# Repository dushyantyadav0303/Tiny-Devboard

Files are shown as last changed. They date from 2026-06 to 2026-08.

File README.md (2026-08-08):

<h1 align="center">
<br> 
<br> Tiny Devboard <br>
</h1>
<div align="center">
  

</div>

<h4 align="center">
A pocket-sized development board built for rapid prototyping, experimentation, and embedded systems development. Its compact USB form factor makes it easy to carry, plug in, and start building wherever inspiration strikes.
</h4>

<div align="center">





</div>

<p align="center">
  <a href="#about-the-project">About</a> •
  <a href="#repository-structure">Structure</a> •
  <a href="#schematic">Schematic</a> •
  <a href="#pcb">PCB</a> •
  <a href="#cad">CAD</a> •
  <a href="#Render">Render</a> •
  <a href="#bill-of-materials">BOM</a> •
  <a href="#license">License</a> •
  <a href="#credits">Credits</a>
</p>  
<p
  align="center">
  

</p>

<br>
<br>
<p align=center>
  
</p>

## About the Project
**Tiny Devboard** is a pocket-sized development board built for rapid prototyping, experimentation, and embedded systems development. Its compact USB form factor makes it easy to carry, plug in, and start building wherever inspiration strikes.

### Specifications

| Item | Details |
|---|---|
| MCU | ATSAMD21E18A-AU |
| Wireless | ESP-12S |
| USB | Type-A |
| Logic Voltage | 3.3V |
| RGB LED | APA102-2020 |
| Programming | UF2 / SWD |

### Features

- **ATSAMD21E18A-AU (32-bit ARM Cortex-M0+)**
- **ESP-12S (ESP8266 Wi-Fi)**
- **USB Type-A Port**
- **RGB Status LED**
- **Compact Form Factor**

## Repository Structure

- `src/PCB/` — EasyEDA project sources
- `src/cad/` — mechanical CAD sources
- `production/pcb/` — PCB fabrication files (Gerbers, BOM, Pick & Place)
- `production/cad/` — 3D-printing files (.3mf)
- `GETTING_STARTED/` — Setup guides, firmware installation, and board bring-up documentation
- `Journal/` — DevLogs With Timestamp
- `Firmware/` — Demo firmware, utilities, and firmware releases for Tiny DevBoard

## Schematic


Source : `src/PCB/Sch`
SCH_Schematic1_1-P1_2026-06-14

## PCB 
Source : `src/PCB/Pcb`
~ https://oshwlab.com/dushyant0303/project_kbwfubeg
<div align="center">

| Front PCB | Back PCB |
|---|---|
|  |  |
|  |  |

</div>

## CAD


A Encloser Case for Tiny Devboard. Case consists of 6 interlocking Hook that are secured them, allowing the enclosure to be assembled without screws or Glue makes it easy assembly.

- source: `src/cad/`
<div align="center">
<table>
<tr>
<td valign="bottom">
</td>
<td valign="bottom">I
</table>
</div>

### 3D-printable Production files are available in:
- source: `production/cad/`

## Render 


<div align="center">
<table>
<tr>
<td valign="bottom">
</td>
<td valign="bottom">
</table>
</div>

## Bill of Materials

Source: `production/pcb/bom.xlsx`

| No. | Quantity | Comment | Designator | Footprint | Value | Price (in INR) | Purchase |
| --- | --- | --- | --- | --- | --- | --- | --- |
| 1 | 1 | 1uf | C1 | C0603 | 1uf | 1.5 | [Buy](https://robu.in/product/cs2012x7r105k500nre-samwha-50v-1uf-x7r-±10-0805-multilayer-ceramic-capacitors-mlcc-smd-smt-rohs/) |
| 2 | 1 | 1.5k | R7 | R0805_NEW | 1.5k | 0.4 | [Buy](https://robu.in/product/wr08x152jtl-walsin-125mw-thick-film-resistors-150v-±100ppm-℃-±5-1-5kω-0805-chip-resistor-surface-mount-rohs/) |
| 4 | 3 | 0.1uf | C8,C5,C7 | C0805 | 0.1uF | 2.1 | [Buy](https://robu.in/product/cl21b104kcc5pnc-samsung-cap-ceramic-0-1uf-100v-x7r-10-pad-smd-0805-omd-cap-125c-automotive-aec-q200-t-r/) |
| 5 | 1 | USB type A port | USB1 | USB-AM-TH_AM90 |  | 14 | [Buy](https://robu.in/product/u-g-04wd-w-03-hroparts-1a-1-4p-male-40℃85℃-type-a-plugin-usb-connectors-rohs/) |
| 6 | 1 | APA102-2020 SuperLED | U2 | LED-SMD_6P-L2.0-W2.0-APA102-2020-SUPERLED |  | 17 | [Buy](https://www.lcsc.com/product-detail/C22439302.html) |
| 7 | 1 | ATSAMD21E18A-AU | U1 | TQFP-32_L7.0-W7.0-P0.80-LS9.0-BL |  | 460 | [Buy](https://www.lioncircuits.com/parts/ATSAMD21E18A-AU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) |
| 8 | 1 | ESP-12S | U4 | WIRELM-SMD_ESP-12S |  | 199 | [Buy](https://robu.in/product/esp-12s/) |
| 9 | 1 | HT7833 | U3 | SOT-89_L4.5-W2.5-P1.50-LS4.2-BR |  | 46 | [Buy](https://robu.in/product/ht7833-holtek-semicon-500ma-fixed-3-3v-positive-electrode-8v-sot-89-3-voltage-regulators-linear-low-drop-out-ldo-regulators-rohs/) |
| 10 | 1 | ZX-PZ1.0-1-6PZZ | Gn +3 Rx Tx Clk Dio | HDR-TH_6P-P1.00-V-F |  | 19 | [Buy](https://robu.in/product/1-month-warranty-884/) |
| 11 | 2 | 0 | R8,R9 | R0603 | 0 | 0.96 | [Buy](https://robu.in/product/ac0805jr-070rl-yageo-res-thick-film-0805-0-ohm-pad-smd-t-r-automotive-aec-q200/) |
| 13 | 2 | LED_0402-R | LED3,LED4 | LED0805-RD_GREEN_C0805YGC |  | 2.6 | [Buy](https://robu.in/product/xl-2012vrc-xinglight-5ma-90mcd-red-lens-615nm630nm-positive-stick-red-120-75mw-2-7v3-3v-0805-led-indication-discrete-rohs/) |
| 14 | 3 | 10uF | C3,C4,C6 | C0805 | 10uF | 1.15 | [Buy](https://robu.in/product/cs2012x7r106k100nre-samwha-10v-10uf-%c2%b110-0805-multilayer-ceramic-capacitors-mlcc-smd-smt-rohs/) |
| 15 | 3 | TSA010A2518A | BOOT,SW1,SW2 | SW-SMD_L4.0-W3.0-LS5.0 |  | 2.1 | [Buy](https://robu.in/product/tsa010a2010a02-bzcn-3mm-2mm-50ma-round-button-standing-paste-3-9mm-100gf-12v-smd-tactile-switches-rohs/) |
| 16 | 6 | 10K | R5,R1,R2,R3,R4,R6 | R0805 |  | 0.61 | [Buy](https://robu.in/product/ac0805fr-7w10kl-yageo-250mw-thick-film-resistors-%c2%b1100ppm-%e2%84%83-%c2%b11-10k%cf%89-0805-chip-resistor-surface-mount-rohs/) |
| 17 | 1 | PCB | | |  | 190  | [Buy](https://jlcpcb.com)|

> [!NOTE]
> Price As of August 8, 2026 
> & It not Include the Shipping fee <br/>

## License

Licensed under MIT — you can use this commercially, modify, and distribute 
with proper attribution. See [LICENSE](LICENSE) file.

## Contributing

Contributions, improvements, and remixes are welcome! Please read the [CONTRIBUTING.md](CONTRIBUTING.md) guide to get started.

## Credits
<div align="center">
  



 
</div>

This project was created during a [Hack Club](https://hackclub.com) event [Macondo](https://macondo.hackclub.com).
- **[EasyEDA](https://easyeda.com)** - PCB design and schematic capture
- **[Fusion 360](https://www.autodesk.com/products/fusion-360)** - Cad Designing
- **[Blender](https://www.blender.org)** - Render
- **[@NotARoomba](https://github.com/notaroomba) & [@Gabouin](https://github.com/Gabouin)** - Readme template

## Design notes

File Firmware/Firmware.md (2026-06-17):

# Tiny DevBoard Firmware Docs

## About

**Tiny DevBoard Firmware** is a demo firmware for the Tiny DevBoard development board Testing, Diagnosing and Check there Capability.
## Workflow 
1. Serial print Banner
2. Initialize GPIO/UART/RGB
3. Check Module Connections
4. Display Hardware Spec
5. Run Self-Test
``` 
Loop
 ├── RGB Animation v
 ├── Status Report
 └── WiFi Scan
 ```
## Quick Start

- Download [Arduino IDE](https://www.arduino.cc/en/software)
- Go to Tools → Board Manager
- Search for "SAMD"
- Install Arduino SAMD Boards by Arduino
- Install Required Libraries
- Go to Sketch → Include Library → Manage Libraries
- Search and install: Adafruit DotStar by Adafruit
- Tools Menu:
``` 
├── Board: Adafruit Trinket M0
├── Serial Monitor Baud: 115200
└── COM Port: 
```
- Open Demo_Firmware.ino file in Arduino IDE
- Click Upload 
- Open Tools → Serial Monitor At baudRate 115200  To See Output

## Expected Output
```
=============================================
                 Tiny Devboard
=============================================
 Firmware Version : v1.0.0
 Build Date       : 10 Jun 2026
 Author           : dushyant.yadav0303

Hola Hackers! It's me tiny devboard
Tiny DevBoard is starting up...

- Starting rgb animation
- Checking USB connection

Resetting Wifi module ...
 - Wifi module detected Successfully

=======================================
System Information
=======================================
Board Name    : Tiny Devboard
MCU           : ATSAMD21E18A-AU
CPU Frequency : 48 MHz
Flash Memory  : 256 KB
SRAM Memory   : 32 KB

 - Wifi module detected Successfully

=========================================
 Board ready to Rock!
=========================================
```

##  Code Structure
```
TinyDevBoard_Firmware.ino
├── Libraries
├── Pin Definitions & Constants
├── Global Variables
├── Function Prototypes
├── setup()
├── loop()
├── Initialization Functions
│   ├── initializeSerial()
│   ├── initializeHardware()
│   ├── initializeRGB()
│   └── initializeESP()
├── Display Functions
│   ├── displayStartupBanner()
│   ├── displaySystemInfo()
│   └── displayStatusReport()
├── RGB Animation Functions
│   ├── updateRGBAnimation()
│   ├── rainbowCycle()
│   ├── breathingAnimation()
│   └── pulseAnimation()
├── ESP Communication Functions
│   ├── communicateWithESP()
│   ├── performWifiScan()
│   ├── sendESPCommand()
│   └── readESPResponse()
└── Utility Functions
    └── getUptimeSeconds()
```

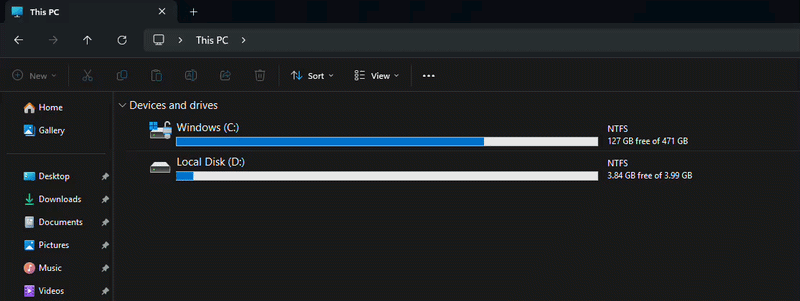
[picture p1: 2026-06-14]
assets/603955411-69c8cde0-e02c-4d08-941e-243680734509.gif

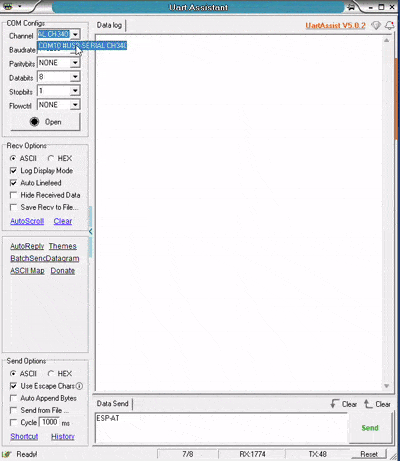
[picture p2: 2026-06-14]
assets/604092013-d6aead8e-e24d-442f-a11d-7670309c13b5.gif

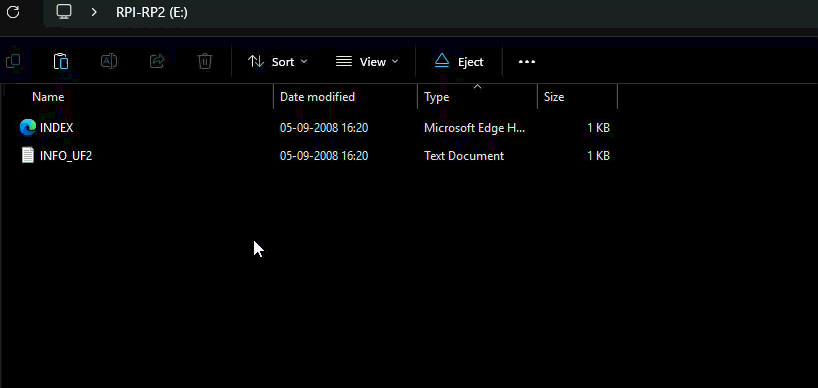
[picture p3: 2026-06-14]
assets/603960065-23f23f05-d857-41ca-997a-91e4c60d457d.gif

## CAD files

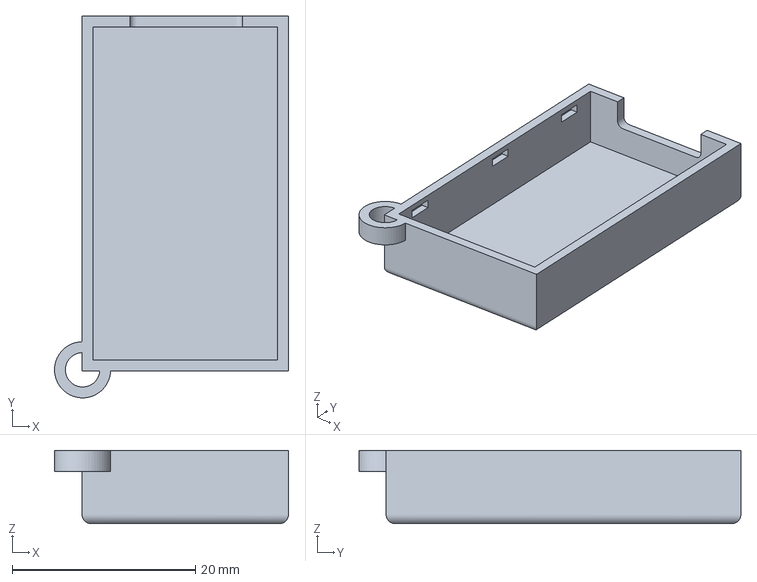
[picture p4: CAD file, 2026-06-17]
production/cad/Bottom.3mf
25.5 x 41.6 x 8.00 mm

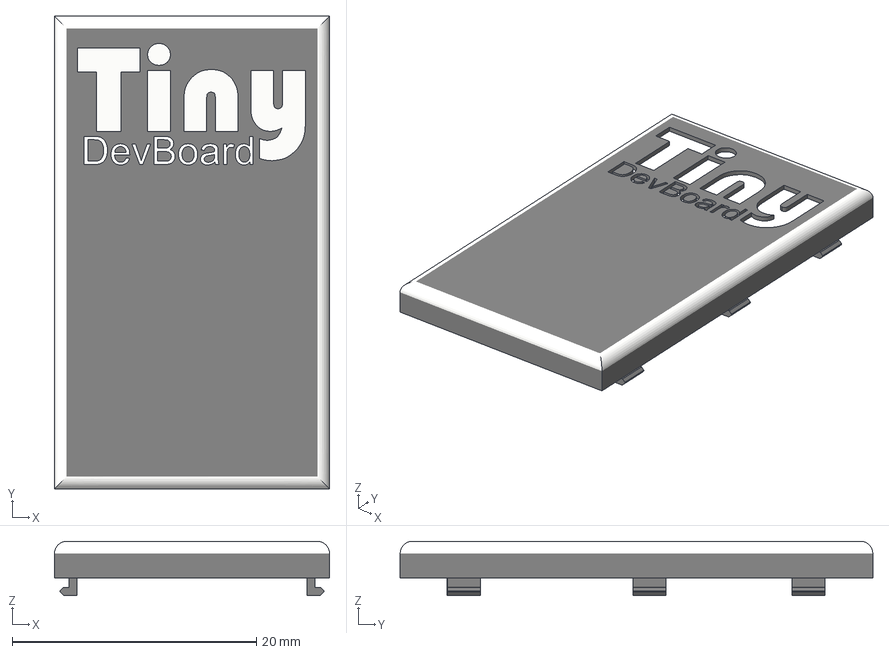
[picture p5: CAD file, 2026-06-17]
production/cad/TOP.3mf
22.5 x 38.7 x 4.45 mm

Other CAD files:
production/cad/stl/Bottom.stl
production/cad/stl/TOP.stl

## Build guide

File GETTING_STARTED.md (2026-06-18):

# Getting Started

## Table of Contents

* [Prerequisites](#prerequisites)

  * [Hardware Requirements](#hardware-requirements)
  * [Software Requirements](#software-requirements)
* [Board Connections](#board-connections)

  * [USB](#usb)
  * [SWD](#swd)
  * [UART](#uart)
* [ATSAMD21 Setup](#atsamd21-setup)

  * [Install Bootloader](#install-bootloader)
  * [Verify Bootloader](#verify-bootloader)
  * [Upload Firmware](#upload-firmware)
* [ESP-12S Setup](#ESP-12S-Setup)

  * [Check Existing Firmware](#check-existing-firmware)
  * [Flash Firmware](#flash-firmware)
* [First Power-On Test](#first-power-on-test)
* [Troubleshooting](#troubleshooting)
* [What's Next?](#What's-Next?)

## Prerequisites
### Hardware Requirements
- [Usb to TTL Converter](https://github.com/dushyantyadav0303/USB-TO-TTL-Convertor)
- [Usb to SWD Converter](https://robocraze.com/products/st-link-v2-v2-1-usb-c-programmer-and-debugger-for-stm32-microcontrollers-7semi)
- [Jumper Wire](https://robocraze.com/products/jumper-wire-set-m2m-m2f-f2f-40-pcs-each)

### Software Requirements

- [Espressif flash download tool](https://docs.espressif.com/projects/esp-test-tools/en/latest/esp32/production_stage/tools/flash_download_tool.html)
- [UartAssist](https://www.nitwo.com/en/download/UartAssist.html)

## Board Connections

### USB
Connect Devboard Usb Port Directly to your Pc


### SWD
> [!WARNING]
> Always Set the adapter TO 3.3v Logic. 

       Devboard                    Usb to SWD
    ┌───────────────┐           ┌─────────────┐
    │ SWDIO         ├──────────►│ SWDIO       │
    │ SWCLK         ├──────────►│ SWCLK       │
    │ 3V3           ├──────────►│ 3V3         │
    │ GND           ├──────────►│ GND         │
    └───────────────┘           └─────────────┘


### UART
> [!WARNING]
> Always Set the adapter TO 3.3v Logic. 

       Devboard                    Usb to TTL
    ┌─────────────┐             ┌─────────────┐
    │          TX ├────────────►│ RX          │
    │          RX │◄────────────┤ TX          │
    │         GND ├────────────►│ GND         │
    │        3.3v ├────────────►│ Vcc         │
    └─────────────┘             └─────────────┘


## ATSAMD21 Setup

### Install Bootloader
1. Connect USB to SWD Converter To DevBoard [Given Above](#swd)
2. Download the [UF2 bootloader](https://downloads.circuitpython.org/bin/trinket_m0/en_US/adafruit-circuitpython-trinket_m0-en_US-10.3.0-alpha.2.uf2)
3. Flash the Bootloader 

### Verify Bootloader
1. Connect the Board via [USB](#usb)
2. Quickly press the RESET button twice 
 

3. Devboard detected in the PC As a external Storage 
Recording2026-06-06223643-ezgif com-speed

### Upload Firmware
1. Connect the Board via [USB](#usb)
2. Quickly press the RESET button twice
4. Prepare your firmware in .uf2
5. Paste your firmware in Detected External storage 


## ESP-12S-Setup

### Check Existing Firmware

1. Connect USB to TTL Converter To DevBoard [Given Above](#UART)
2. Download Serial Port Terminal ex. [UartAssist ](https://www.nitwo.com/en/download/UartAssist.html)
3. Configure it According to this 


4. Send AT command 
Recording 2026-06-07 035755 - Trim

If you Response Ok Then it is Perfect 
If not then Follow next [Flash Firmware](#flash-firmware)

### Flash Firmware

1. Download [Firmware](https://espressif-docs.readthedocs-hosted.com/projects/esp-at/en/release-v2.3.0.0_esp8266/AT_Binary_Lists/ESP8266_AT_binaries.html) 
2. Download [Espressif flash download tool](https://docs.espressif.com/projects/esp-test-tools/en/latest/esp32/production_stage/tools/flash_download_tool.html) 
3. Connect USB to TTL Converter To DevBoard [Given Above](#UART)
4. Open Flashing tool 
- Select Esp8266 & Developer mode 


- Select the firmware with hex code 0x0 & And select the Correct com Port


5. Esp-12s into Flash mode


- Press and hold the BOOT button
- Press and release the RST button
- Release the BOOT button
Then Click Start 

## First Power-On Test
First Power-On Test - It is a test To verify whether All the function in the they board are running properly. By flashing **Demo firmware** in Tiny drvboard.

### Flashing demo firmware 
- Download [Demo Firmware](Firmware/Demo_Firmware.ino) from [Firmware directory](Firmware/Firmware.md) 
- Connect the Board via [USB](#usb)
- Quickly press the RESET button twice
- Paste the Demo firmware in Devboard

### Expected Behavior
After uploaded the demo firmware The devboard Starts:
- Rgb led animation
- Wifi Module Status
- Wifi Scan 
- Serial print Status 

### Expected Serial-Print 
```text
=============================================
                 Tiny Devboard
=============================================
 Firmware Version : v1.0.0
 Build Date       : 10 Jun 2026
 Author           : dushyant.yadav0303

Hola Hackers! It's me tiny devboard
Tiny DevBoard is starting up...

- Starting rgb animation
- Checking USB connection

Resetting Wifi module ...
 - Wifi module detected Successfully

=======================================
System Information
=======================================
Board Name    : Tiny Devboard
MCU           : ATSAMD21E18A-AU
CPU Frequency : 48 MHz
Flash Memory  : 256 KB
SRAM Memory   : 32 KB

 - Wifi module detected Successfully

=========================================
 Board ready to Rock!
=========================================

```

## Troubleshooting 

### No Serial Output
---------------------

- Verify the USB cable supports data transfer.
- Ensure the correct COM Port is selected.
- Press the RESET button and reconnect the board. 

### Wifi module not detected 
----------------------------

- [Verify the ESP-12S firmware](#check-existing-firmware) is installed.
- Check the UART connection between the ATSAMD21 and ESP-12S.

### RGB LED Not Working
-----------------------

- Verify the demo firmware was uploaded Properly.
- Press the RESET button to restart the Script.

## Still Need Help?
If you're experiencing an issue that is not covered in this guide, 
please open a GitHub Issue. 

## What's Next?
Your board is now set up and ready for development.
Now, It is Your Duty to begin creating your own Amazing Project using the Tiny Dev-Board, or explore & learn more about the board's capabilities.
Happy hacking!

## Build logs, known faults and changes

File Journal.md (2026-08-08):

# printed case

**Author:** dushyant.yadav0303
 
**Time Logged:** 0.2h

---
# yoooooo gng,
## Finally I received the 3D printer
```
 \^o^/ 
```

## Second I print was this tiny devboard case because first was Benchy {I was follow the Traditional activity} 
### next i click few photo of it.



# Now I proudly say it is completed.
## Now just making a demo video and updating the repo left

---

# Uploading  Firmware + Troubleshoot

**Author:** dushyant.yadav0303
 
**Time Logged:** 1.2h
---
## hola gng I'm working with firmware flashing in which i am totally following the same Instructions that I given in [Getting Started](https://github.com/dushyantyadav0303/Tiny-Devboard/blob/main/GETTING_STARTED.md)
## there is some mistake in Pin define which I fixed 
## here you see my setup (the black chip was a USB to TTL converter)


---

# Soldering

**Author:** dushyant.yadav0303
 
**Time Logged:** 

---
# Yooo! today I'm doing the Assembly or you say Soldering of all the Component 
## First I sort all the Component {Why Robu.in not Mention the Value on Package :( } 
## Next i Printout the BOM & PCB image and stick all the component Respectively on it vv

## Next i Collect all the Equipment and cover my desk with Paper (otherwise my mom will beat me lol)

# now ready for soldering !
### It is kinda Difficult to solder tiny component with out Microscope 
## also I lost my Precise Tweezer /_ \
### which make it more difficult. I bend the diode legs and use it as tweezer
## after Hella of time i Finally solder up the component 


## Next i hide dogesh logo with MCU finally and completed the board

---

# what happen to my order?

**Author:** dushyant.yadav0303
 
**Time Logged:** 

---
# hello 
## It's almost a month from last update "Order all the Component" 
## Here is good news I Receiver 2/3 order 
## which Include:
- Components

- PCB

# Now what happen to my 3/3 order
## I order it from lions Circuit, there are importing component to india and Domestically deliver in India.
## I get an update on 23 that "your order get lost in transit, We'll Initiate your refund in few days"

# Not the Biggest problem comes How I get this MCU now !!!!
## lions Circuit is the one on that i trust. also Mouser and digikey are trust but not good price for single pcs order- shipping fee is more than product price.
# After 3-5 hours of researching,
### i not find any store where i get this ╯︿╰ 
### good news this same Ic use in Adafruit QT Py devboard.
### so my planning to Do transplant surgery. hehehehe
## I ordered that board:


---

# Order all the Component.

**Author:** dushyant.yadav0303
 
**Time Logged:** 1.4h

---
# Yesterday{sorry I'm late}, I order all the Component.
## Sound easy, But not For India Cause many Item are Not Available Or Over Price, Importing from Abroad It's kinda risky. Cause Custom Duty/Taxes Are Unpredictable.
### I'm Splitting product list in three parts - Available & Alternative
# Available
- Micro component like Resister, capacitors & led is Easily available And I order from [Robu.in](https://robu.in)

- MCU -> 1. Esp 12s Is easily available from [Robu.in](https://robu.in) but
 2. ATSAMD21 Is Little bit expensive + Only available on one store [lioncircuits](https://www.lioncircuits.com)

# Alternative 

### A90 USB isn't Available in India 


### After exploring a market a lot I finally get The alternative with the same dimensions but It is ****expensive****.


### After spending a lot more time I finally get The same dimension and the cheaper option


---

# Order PCB!

**Author:** dushyant.yadav0303
 
**Time Logged:** 0.5h

---

## While I'm ordering the PCB I found that The USB footprint Interrupting the PCB Border outline

## So before ordering it I fix the footprint And Update it on Github 

## Place the order From [jlcpcb](https://jlcpcb.com)


---

# Thank you!

**Author:** dushyant.yadav0303

**Time Logged:** N/A

---

# This is not just a project. It teaches me lot of Skills, Mistakes & Way of Thinking.

# Also I love Show and tell



### Also I want to thanks my motivators, that Motivate me Across the journey-

# @Gabin



# @NotARoomba





# @Rohan







---

# Completed Repo!

**Author:** dushyant.yadav0303
 
**Time Logged:** 1.1h

---

## Today, I finalize the github Repo

- Starting with CONTRIBUTING.md



- Then Uploaded SRC and Production Files



- Then Made the Journal.md which include all the Journal I Logged At Macondo Platform
Uploaded Soon!

---

# Firmware

**Author:** dushyant.yadav0303
 
**Time Logged:** N/A

---

# Note : Firmware Time is Tracked via Hackatime

# Today, I Start Working on Firmware part Which include:

- Demo Firmware

- Firmware.md



## Demo Firmware - is a demo firmware for the Tiny DevBoard development board Testing, Diagnosing and Check there Capability.

### Tests

- Rgb led animation

- Wifi Module Status

- Wifi Scan

- Serial print stasis



## Firmware.md- is a Guild For Flashing Firmware includes:

- Install Library

- Install Board

- Workflow

- Code architecture

---

# Readme Completed!

**Author:** dushyant.yadav0303
 
**Time Logged:** 0.4h

---

Today, I Work on the Remaining Over work in Readme.md

- Added the BOM



- Added the License + Contributing + Credits



---

# Readme #4

**Author:** dushyant.yadav0303
 
**Time Logged:** 1h

---

# Today, I start with Creating the Badges

## I useshieldsto Create badges.

### Here is For easyeda



### Here is For Fusion360



### Here is For Blender



### It looks Simple, And it is Simple but not For the Hackclub Macondo Badge cause of logo and Color blending. I not gonna lie it Takes 1.2hr just for Hackclub badge but I don't have Lapse So i Not Adding it. Otherwise it Might be Inflated



### Anyway Enjoy the Macondo Badge



### Readme.md









---

# Readme #3

**Author:** dushyant.yadav0303
 
**Time Logged:** 1.2h

---

# Today I start working on my ProjectReadme.md

### I started with Adding specification Of Tiny-Devboard In About Section



### I Added the PCB Image with and Without Silkscreen



### Next I added The Cad and Render Also plus I try a Alot to Auto play the Gif but It is Not AutoPlay.



---

# ‎ ‎Yeah! I win Show and Tell #5

**Author:** dushyant.yadav0303
 
**Time Logged:** N/A

---

# Yeah! I win Show and Tell #5 For This project.

### It's my First Time Attending show and tell, And it is very wonderful experience To see other project & Effort & show our project plus I'm nervous to show my project.

### After the voting ended, It's time to announce the final winner.

### Then I heard My Project Name -Tiny DevBoard

## Winning was an surprise and memorable moment for me. Thank you to everyone who supported and voted for the project!.



---

# ‎ ‎‎Readme #2

**Author:** dushyant.yadav0303
 
**Time Logged:** 1h

---

# Today I start working on my ProjectReadme.md

## About the Project

- First I work on About the project Which Includes Project name and Description. Next I added All the Features of the Devboard
Here Is Readme.md



- Then I Added the systematic of the PCB including Sorce
Here Is Readme.md



---

# ‎ ‎‎Readme #1

**Author:** dushyant.yadav0303
 
**Time Logged:** 1.9h

---

Today I start working on my Project Readme.md

- I started with preparing Board logo

- First I make a design in Fusion 360 in which the Base is Going to Be Matte Black and Logo In Golden Color

### Here is 3D model:



- Then I Render the 3d model

### Here is the final logo



- Then I add it Into the Readme

- Also add Toc, Badges, Banner & Description Into the Readme.

### Here isReadme.md



---

# ‎ ‎‎Getting Started Completed!

**Author:** dushyant.yadav0303
 
**Time Logged:** 0.9h

---

## Today, I Add Connection Diagram & RecheckGetting-Started.md

- First I Make the Connection Diagram In Figma  For the Uart and Swd Communication.

### Here I added the Diagram :



- Then I recheck all the things And here we go We finally complete our getting started file At the end I can say It is too much Polish And best for beginners.

---

# Getting Started #5

**Author:** dushyant.yadav0303
 
**Time Logged:** 1.4h

---

Today, I work on **First Power-On Test** & **Troubleshooting**

- I added **the First Power-On Test** To quickly test The tiny devboard And diagnose the issue.

- Then I added **Troubleshooting** In which I added all the Possible Issue But still if it not there Then they can just Issue on github

- Really it is too Beginner friendly!

# Here is Getting Started:





---

# weekly journal

**Author:** dushyant.yadav0303
 
**Time Logged:** N/A

---

### Yah!!! We Again Get into weekly journal. It really Motivates me for building more crazy project.

Thank you! @Gabin



---

# Getting Started #4

**Author:** dushyant.yadav0303
 
**Time Logged:** 2.6h

---

Today, I Make a **Render Animation** to Show how to Put **Esp-12s into Flashing Mode**.

Basically we have to put Esp-12s into flashing mode Before uploading the firmware.

### How to do it -

- Press and hold the BOOT button

- Press and release the RST button

- Release the BOOT button

Which is little Confusing for the **beginner/Non-technical person**, cause There is **2 Reset Button** on the board. For that I prepared the animation In **Blender**.

## Setup



## Render



## Here is Getting Started:



---

# Getting Started #3

**Author:** dushyant.yadav0303
 
**Time Logged:** 2.3h

---

Today I am Working on the **ESP-12S Setup**

- First I Read the Docs of espressif AT Firmware in Depth.

- Then I Start testing it with my Esp32 dev board Right now I don't have Esp12-s But it is almost similar For both. (It is Really necessary to test the thing Before Shipping cause Every time The things are not going to works mentions in Docs)



- I start working on Making the guide.

- Again I record Video Clips and Attached with the guide which Makes it's very easy to understand.

## Here is Getting Started:





---

# Getting Started #2

**Author:** dushyant.yadav0303
 
**Time Logged:** 2.4h

---

Today I am Working on the **ATSAMD21 Setup Guide**

- First I Done a research about Flashing the UF2 bootloader

- then I start gathering All the source link For downloading and required software. Which overall help the User Especially Beginner To download all the files

- I write up all the Guide

- Then I record the Clips and And attach with Steps. Which is Really help For Beginner.

# Here is Getting Started:



---

# Getting Started  #1

**Author:** dushyant.yadav0303
 
**Time Logged:** 2.1h

---

I want to Make as much has possible **beginner friendly**. That's why I start preparing Startup Guide or Say Getting started.
And for make it very easy to understand I Making Render Animation Clips.

## Render

Even it is simple but the Laptop 3d model I use have Too much detailing. which **Crash my PC** multiple time After changing Settings I finally get the output.



# Here is Getting Started:





---

# Adding Programming Pin

**Author:** dushyant.yadav0303
 
**Time Logged:** 0.8h

---

While Making Set up guide. I found out **Atsamd21e18A-AU** Not support **UART Serial communication ** To flash the Firmware via Default Bootloader , But we To flash UL2 Bootloader So I added SWD Pin For For flashing the  Firmware via **Serial Wire Debug Protocol**.

## Here is the updated systematic

(Also the Red marks determined that things updated)



## Where is the updated PCB

Proof of Time **POT**: It take little bit longer than usual cause this project I already Uploaded on the oshwlab as Told in previous log So to fix it there too takes a bit & I also learn The difference between them .



---

# Firmware

**Author:** dushyant.yadav0303
 
**Time Logged:** 1.2h

---

In this DevBoard we have 2 MCU

- Esp-12s: As a Wifi Module

- Atsamd21e18A-AU: Main processing unit

## For Esp-12s

By default There is a **AT firmware** install in esp-12s Which help Use it as Wifi module via Serial communication protocol.

But in Rare cases It Get erase For that I am Prepare a guide to burn the Firmware into Esp-12s

## For Atsamd21e18A-AU

We have to flash UF2 bootloader help to Directly Connect to Pc and Upload the Code.

And for access Wifi we have to use AT command

Example to connect with Wifi

AT+CWMODE=1
AT+CWJAP="WiFiName","Password"

Source - espressif



---

# Completed Render animation (banner)

**Author:** dushyant.yadav0303
 
**Time Logged:** 2.8h

---

Finally after spending two days To learn & Make this Render but the result are too crazy I don't believe I can made a Company like Render at my home, It is it is too awesome. Just check it out!!

# Here I am presentingtiny DevBoard



## Setup



---

# Making Render animation

**Author:** dushyant.yadav0303
 
**Time Logged:** 2.2h

---

Right now it is under Building And I don't want to disclose it right now It really very crazy And I hope you like it When it Public



---

# CAD

**Author:** dushyant.yadav0303
 
**Time Logged:** 3.2h

---

Today I am Start Designing the case for the Devboard But this time I want it Have a snapfit feature, Instead of Screwing it.

### Here is the main thing which take a lot Or We say a ton of time



### I add 6 Snap fit Lock



### Here is Complete look



### Then i add color



---

# Posted On oshwlab

**Author:** dushyant.yadav0303
 
**Time Logged:** 0.7h

---

After asking On #macondo-help For "Does i use oshwlab for Demo link" and they Allow me then I post all the file and detail over there

# LINK



---

# Render

**Author:** dushyant.yadav0303
 
**Time Logged:** 2.4h

---

After all this completed I prepared the Render Of the Tiny Dev-board PCB In blender. I also add the Green Crafting Mat At Bottom To give DIY Vibe,
Also added Light in all the led You look more professional.



## Here is the setup



## Render





---

# Recover your Project

**Author:** dushyant.yadav0303
 
**Time Logged:** 0.4h

---

In between of My Work By mistake I suddenly closed the Tab And this is the EasyEDA online version Running on browser.
And really scare me cause I not Save my Project, Then I start exploring EasyEDA Then I find this option:

# Files --> Cache Recovery --> Select Project --> Select TimeStamp --> Click on recovery

<3







---

# Silkscreen

**Author:** dushyant.yadav0303
 
**Time Logged:** 1.8h

---

I properly arrange the value and reff* So it is Easy to identify then And Look Clean.

Then I add the image of dogesh. Dogesh is nothing, just Dog it is going viral on internet With the name Dogesh.

To make it Multi color I split it into 3 Part And this is my first time to doing Multi Layer Image ( And it is really too confusing to choose which Part of which layer )









## Then here is the final result



---

# Optimizing space & Changing Footprint

**Author:** dushyant.yadav0303
 
**Time Logged:** 1.7h

---

After routing the PCB found out there is a lot of space Remain in the PCB Which can be used to optimize a Space in PCB. After rearranging some components and routing the PCB again. I make it more smaller.

### Here you see



**Also**
Previously I just put Add Raw pads Which I short with a help of tweezer while flashing the Firmware to put it Boot mode then I plan to Real Tactile switch cause it Not taking Huge space Add easy to use, After rearrange Some more component I finally somehow fit it in PCB Without changing there Size.

### Here you See





---

# Routing the PCB

**Author:** dushyant.yadav0303
 
**Time Logged:** 2.5h

---

Now finally Let's route this PCB Which is the My Favourite part of PCB Designing,
For Copper pour the Net for top is Gnd and For Bottom Net is 3v.

### Here is the result of routing the PCB





---

# Layout the PCB

**Author:** dushyant.yadav0303
 
**Time Logged:** 1h

---

# Today I start designing the PCB

## Let's first layout The PCB. While doing it I Keep this in mind -

- It is important to arrange the capacitors Efficiently.

- Make a Compact as possible

- The component not interfere to Other

### Here is the final result of Layout



---

# Streamline Systematic

**Author:** dushyant.yadav0303
 
**Time Logged:** 1.2h

---

Yesterday, i complete the Rough systematic, Today i am Adding Comment and Symbol So it is easy to understand.

### Here is final Systematic



---

# Prepare systematic

**Author:** dushyant.yadav0303
 
**Time Logged:** 3.7h

---

Finally conducting all this research & reading the data sheets I finally Made the systematic Of the Compact-Devboard Or you say **rough systematic**. Right now it is difficult to understand for a beginner. Overall Moral of the story- **Don't stuck with Esp32 Explore other boards too** It is Little bit different to Put Esp12E in Boot-MODE

### Overall Here is Rougf systematic



## Source

ESP-12S-datasheets

Atsamd21e18A-AU datasheet

---

# Research

**Author:** dushyant.yadav0303
 
**Time Logged:** 1.6h

---

After Conducting a Research,

My requirement Is the compact Size Which we can carry and move around Anywhere.

I Plan to use ATSAMD21E18 which help In high speed communication. As the Have pros It also have corns It don't come with Wi-fi module To fulfill that gap, I plan to Integrate Wifi with the help of Esp 12S. Overall Both together make a good combo.

### here is Flow chart

USB --> ATSAMD21E18 --> Esp 12s --> Wifi

Both processor with the Serial communication protocol,

Sorry, I created a little bit of image But it is not important believe me.



python extract_journals.py input.html

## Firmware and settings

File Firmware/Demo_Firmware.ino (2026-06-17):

/*
* ========================================
* TINY DEVBOARD - Demo FIRMWARE 
* ========================================
*
* Simple , easy-to-understand firmware for Tiny DevBoard
* Microcontroller : ATSAMD21E18A-AU
* Wifi Module : ESP-12S  via AT Command
*
* Author : dushyant.yadav0303
* Build Date : 15 Jun 2026
*=========================================
*/

#include <Adafruit_DotStar.h>
#include <SPI.h>

// pins

#define RGB_DATA_PIN    PA00
#define RGB_CLOCK_PIN   PA01
#define ESP_RX_PIN      PA06
#define ESP_TX_PIN      PA07
#define ESP_RESET_PIN   PA17
#define STATUS_LED_PIN  PA10
#define SERIAL_BAUD_RATE     115200
#define ESP_BAUD_RATE        115200
#define RGB_PIXELS           1
#define STATUS_INTERVAL      10000  
#define WIFI_SCAN_INTERVAL   30000

adafruit_DotStar strip( RGB_PIXELS , RGB_DATA_PIN, RGB_CLOCK_PIN, DOTSTAR_BRG ) ;
Uart ESP_SERIAL(&sercom1, ESP_RX_PIN, ESP_TX_PIN , SERCOM_RX_PAD_3, UART_TX_PAD_0 );

unsigned long startTime = 0 ;
unsigned long lastStatus = 0 ;
unsigned long lastWifiScan = 0 ;
unsigned long animationTimer = 0 ;

uint8_t espDetected = 0 ;
uint8_t currentColor = 0 ;

char wifiNetworks [5][50] ;
int8_t wifiRSSI[5] ;
uint8_t networkCount = 0 ;

uint32_t colors[] = {0xFF0000, 0x00FF00, 0x0000FF, 0xFFFFFF, 0xFF00FF};
uint8_t colorCount = 5 ;

void setup(){
    Serial.begin(SERIAL_BAUD_RATE);
    pinMode(STATUS_LED_PIN, OUTPUT);
    pinMode(ESP_RESET_PIN, OUTPUT);
    delay (1000);
    strip.begin();
    strip.show();
    startTime = millis();
    displayStartup();
    initializeESP();
    displaySystemInfo();
}

void loop (){
    unsigned long currentTime = millis ();
    updateRGBAnimation ( currentTime ) ;
    if (currentTime - lastWifiScan >= WIFI_SCAN_INTERVAL) {
     lastWifiScan = currentTime;
     scanWifiNetworks();
    }
    if ( currentTime - lastStatus >= STATUS_INTERVAL) {
        lastStatus = currentTime ;
        displayStatus(currentTime);
    }

    digitalWrite(STATUS_LED_PIN,(currentTime / 1000) %2 == 0 ? HIGH : LOW );
    delay(50);
}
void displayStartup(){
     Serial.println();
     Serial.println("=============================================");
     Serial.println("                 Tiny Devboard               ");
     Serial.println("=============================================");
     Serial.println(" Firmware Version : v1.0.0");
     Serial.println(" Build Date       : 10 Jun 2026 ");
     Serial.println(" Author           : dushyant.yadav0303 ");
     Serial.println();
     Serial.println("Hola Hackers! It's me tiny devboard ");
     Serial.println("Tiny DevBoard is starting up...");
     Serial.println();
     Serial.println("- Starting rgb animation");
     strip.setPixelColor(0, 0xFF0000);
     strip.setBrightness(255);
     strip.show();
     delay(300);

     Serial.println("- Checking USB connection ");
     delay(300);
}  

void displaySystemInfo(){
    Serial.println();
    Serial.println("=======================================");
    Serial.println("System Information");
    Serial.println("=======================================");
    Serial.println("Board Name    : Tiny Devboard");
    Serial.println("MCU           : ATSAMD21E18A-AU");
    Serial.println("CPU Frequency : 48 MHz");
    Serial.println("Flash Memory  : 256  KB ");
    Serial.println("SRAM Memory   : 32 KB");
    Serial.println();

    if(espDetected){
        Serial.println(" - Wifi module detected Successfully");
    } else {
        Serial.println(" - Wifi module not detected");
        Serial.println("Check Getting Start - Troubleshoot section");
    }

    Serial.println();
    Serial.println("=========================================");
    Serial.println(" Board ready to Rock!");
    Serial.println("=========================================");
    Serial.println();
}

void displayStatus(unsigned long currentTime){
    unsigned long uptime = (currentTime - startTime) / 1000;
    Serial.println();
    Serial.println("==========================================");
    Serial.println("Board Status Report");
    Serial.println("==========================================");
    Serial.println(" Uptime              :  ");
    Serial.println(uptime);
    Serial.println("seconds");
    Serial.println("RGB Animation        :  ");
    Serial.println("Running");
    Serial.println(" ESP Communication   :  ");
    if (espDetected){
        Serial.println("OK");
    } else {
        Serial.println("Not Available");
    }
    Serial.println("=========================================");
    Serial.println();
}

void updateRGBAnimation(unsigned long currentTime){
    static unsigned long lastColorChange = 0;
    if (currentTime - lastColorChange >= 3000){
        lastColorChange = currentTime;
        currentColor++;
        if (currentColor >= colorCount){
            currentColor = 0 ;
        }
        uint32_t color = colors[currentColor];
        strip.setPixelColor (0, color);
        strip.setBrightness(255);
        strip.show();
    }
}

void initializeESP(){ 
    Serial.println("Resetting Wifi module ...");
    pinPeripheral(ESP_RX_PIN, PIO_SERCOM);
    pinPeripheral(ESP_TX_PIN, PIO_SERCOM);
    ESP_SERIAL.begin(ESP_BAUD_RATE);
    digitalWrite(ESP_RESET_PIN, LOW);
    delay(100);
    digitalWrite(ESP_RESET_PIN, HIGH);
    delay(500);

    while  (ESP_SERIAL.available()){
        ESP_SERIAL.read();
    }

    delay(500);
    sendCommand("AT");
    String response = readResponse(2000);

    if (response.indexOf("OK") != -1){
        espDetected = 1;
        Serial.println(" - Wifi module detected Successfully");
    } else {
        espDetected = 0 ;
        Serial.println(" - Wifi module Not detected");
    }
        Serial.println();
}

void scanWifiNetworks(){
    if (!espDetected){
        return;
    }
    Serial.println("- Wifi scan completed :");

    sendCommand("AT+CWMODE=1")
    readResponse(500);

    sendCommand("AT+CWLAP");
    String response = readResponse(3000);

    parseWifiResponse(response);

    if (networkCount > 0 ){
        for (uint8_t i = 0; i < networkCount; i++){
        Serial.print(" ");
        Serial.print(i + 1);
        Serial.print(". ");
        Serial.print(wifiNetworks[i]);
        Serial.print("  (");
        Serial.print(wifiRSSI[i]);
        Serial.println(" dBm)");
        }
    }
            Serial.println();
}

void parseWifiResponse(String response){
     networkCount = 0 ;

     int startPos = 0 ;
     while (networkCount < 5) {

        int cwlapPos = response.indexOf("+CWLAP:", startPos);
        if (cwlapPos == -1 ) break;

        int ssidStart = response.indexOf("\"" , cwlapPos);
        if (ssidStart == -1 ) break;
        ssidStart++;

        int ssidEnd = response.indexOf("\"" , ssidStart);
        if (ssidEnd == -1 ) break;

        String ssid = response.substring(ssidStart, ssidEnd);
        ssid.toCharArray(wifiNetworks[networkCount], 50);

        int rssiStart = response.indexOf("," , ssidEnd);
        if (rssiStart == -1 ) break;
        rssiStart++;

        int rssiEnd = response.indexOf(",", rssiStart);
        if (rssiEnd == -1 ) {
            rssiEnd = response.indexOf(")", rssiStart);
        }
        if (rssiEnd == -1) break;

        String rssiStr = response.substring(rssiStart, rssiEnd);
        wifiRSSI[networkCount]= rssiStr.toInt();

        networkCount++;
        startPos = rssiEnd;
     }
}

void sendCommand(const char*command){
    while (ESP_SERIAL.available()) {
         ESP_SERIAL.read();
    }
    ESP_SERIAL.print(command);
    ESP_SERIAL.print("\r\n");
    ESP_SERIAL.flush();
    delay (50);
}

String readResponse(unsigned long timeout) {
    String response = "";
    unsigned long startTime = millis();

    while (millis() - startTime < timeout) {
        while (ESP_SERIAL.available()) {
            char c = ESP_SERIAL.read();
            response += c;
            startTime = millis();
        }
    }

    return response;
}
 
void pinPeripheral (uint32_t ulPin, EPioType ulPeripheral) {
    PORT ->
    Group[ g_APinDescription[ulPin].ulPort].PINCFG[g_APinDescription[ulPin].ulPin].bit.PMUXEN = 1;
    PORT ->
    Group[g_APinDescription[ulPin].ulPort].PMUX[g_APinDescription[ulPin].ulPin >> 1].reg =
    (PORT ->
    Group[g_APinDescription[ulPin].ulPort].PMUX[g_APinDescription[ulPin].ulPin >> 1].reg &
    (0xF << ( 4* (g_APinDescription[ulPin].ulPin & 0x01)))) |
    (ulPeripheral << (4 * (g_APinDescription[ulPin].ulPin & 0x01 )));
}

 void SERCOM1_Handler(){
    ESP_SERIAL.IrqHandler();
}

/*
It is Your Duty to begin creating your own Amazing Project using the Tiny Dev-Board While Taking Firmware as Reference,
And explore & learn more about the board's capabilities.
 Happy hacking!
If you're experiencing an issue that is not covered in this guide, please open a GitHub Issue.
*/

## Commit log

2026-08-08 Final bom.csv
    [BOM.csv]
2026-08-08 Update Journal
    Added detailed journal entries documenting the progress of 3D printing, firmware flashing, soldering, and component ordering.
2026-08-08 add final BOM with buy links
2026-08-08 add final bom with link
    Added PCB entry with price and purchase link to the components list.
2026-08-08 Update PCB source link
    Added link to PCB source in README

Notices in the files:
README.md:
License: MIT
